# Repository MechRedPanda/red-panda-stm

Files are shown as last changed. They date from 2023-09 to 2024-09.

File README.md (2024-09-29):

# Mechanical Panda's Scanning Tunneling Microscope (STM) Design

This repository contains the design files for Mechanical Panda's Scanning Tunneling Microscope (STM), including Fusion360 CAD files, PCB engineering files, C++ firmware, and the Python software used to control the STM.

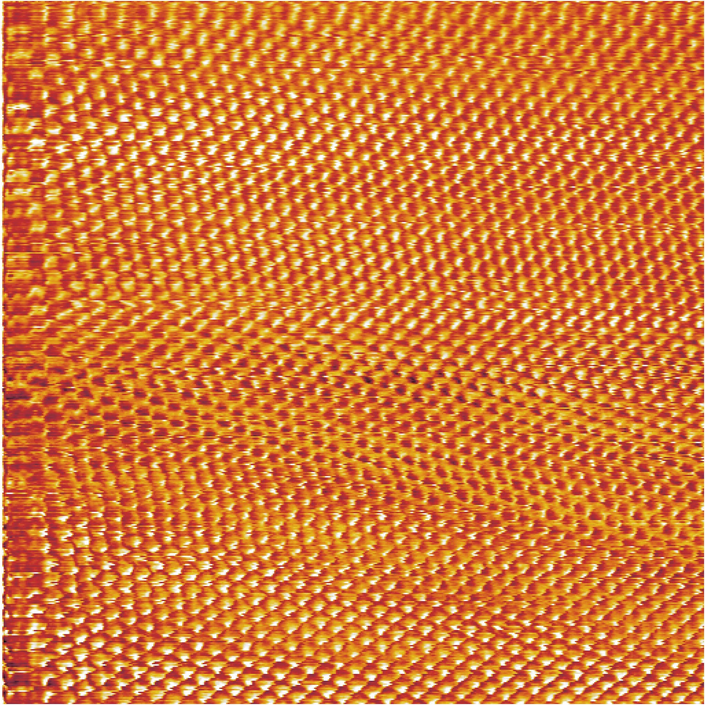
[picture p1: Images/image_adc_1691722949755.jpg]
HOPG Image of Carbon Atoms on Graphite Surface Captured by Mechanical Panda's STM

_Image of carbon atoms on the surface of graphite, showing the hexagonal structure of carbon atoms, captured by Mechanical Panda's STM._

## Project Overview

This world’s first STM design uses FDM 3D-printed parts as the main structural components. The STM can achieve atomic-level resolution, allowing it to image individual atoms.

Currently, no detailed step-by-step build tutorial is available. However, you can find a comprehensive project overview in the video on Mechanical Panda's channel:  

[**[Building a 3D Printed Atomic-Resolution Scanning Tunneling Microscope (STM) | DIY STM Explained]**]([https://www.bilibili.com/video/BV1p94y1z7jX/?share_source=copy_web&vd_source=77fd182a5182be115284bbe426944568](https://www.youtube.com/watch?v=7N3OqTEq08g))

The overall design and inspiration for this project were primarily based on Dan Berard's home-built STM project, which you can find here:  
[**[Dan Berard's Home-Built STM]**](https://dberard.com/home-built-stm/)

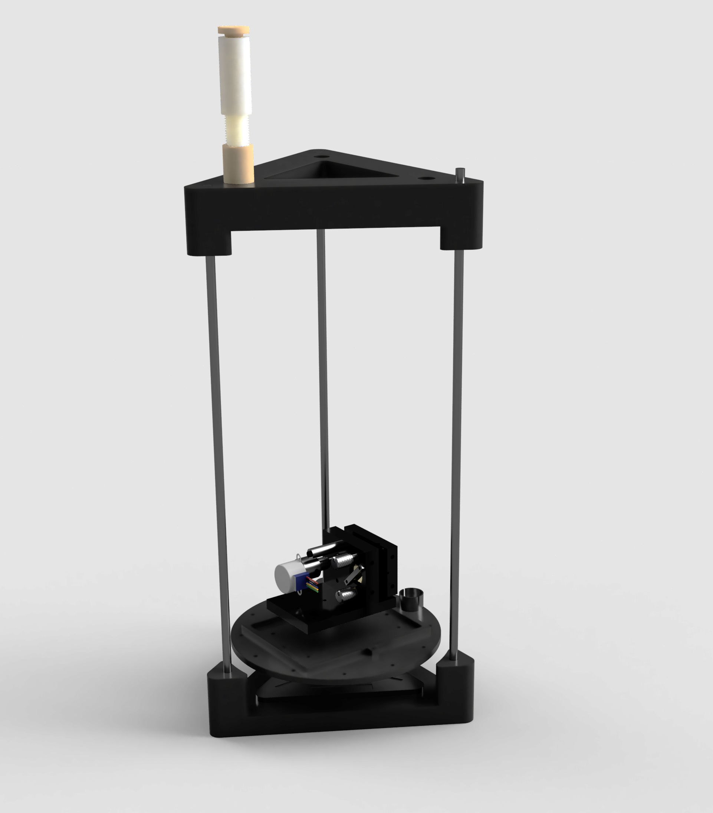
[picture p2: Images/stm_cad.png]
CAD CAD Files of the STM

_CAD files of the STM, including the STM body and vibration isolation platform._

## Repository Contents

- **Fusion360 CAD Files**: Full 3D models of the STM, including the main STM body and the vibration isolation system.
- **PCB Engineering Files**: PCB designs for the pre-amplifier and control circuit used in the STM.
- **C++ Firmware**: Microcontroller firmware for real-time control of the STM.
- **Python Control Software**: Python software for interfacing with the STM, including GUI control and data processing.

## How It Works

This STM uses a 3D-printed unimorph disk scanner, based on piezoelectric ceramics, for sub-nanometer movement. The sharp tungsten tip moves laterally across the sample's surface while measuring tunneling current to map atomic structures. A Teensy 4.1 microcontroller controls the scanner and collects scan data, while a Python program processes the data to produce high-resolution images of atomic structures.

## Acknowledgments

This project would not have been possible without the work and inspiration from Dan Berard's STM project. A huge thank you for sharing detailed reference materials that helped shape this design.

## Future Work

- **Add BOM List**: A Bill of Materials (BOM) for all the parts needed to build this STM will be added soon.

## Disclaimer

This project is experimental and requires a strong understanding of STM technology, electronics, and 3D printing. Building an STM can be challenging, but if you love pushing the boundaries of what hobbyists can achieve, this project is for you.

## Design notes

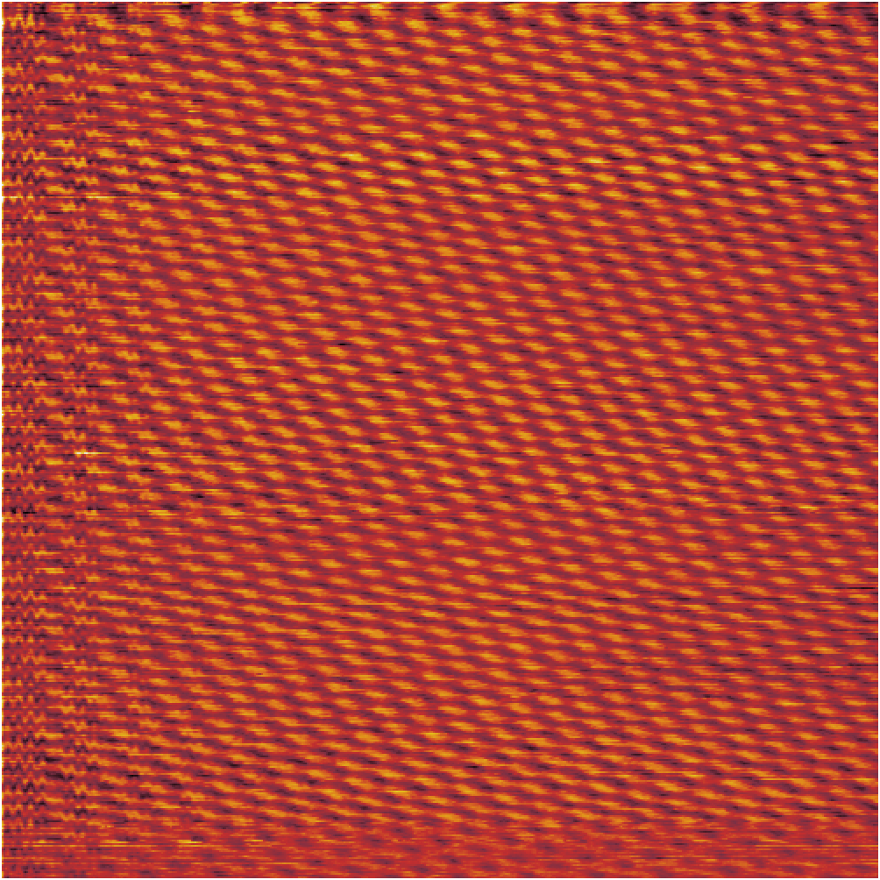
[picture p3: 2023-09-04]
Images/image_adc_1691787217383_high_res.bmp

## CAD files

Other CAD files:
CAD/STM.f3z

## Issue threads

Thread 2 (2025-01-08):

Question: Switching over to Kicad?

polymurph, 2025-01-08:
First off... I saw the [youtube](https://www.youtube.com/watch?v=7N3OqTEq08g) video. Great job. I wanted to ask if you intend to go on in the future with Kicad for the PCB designs.

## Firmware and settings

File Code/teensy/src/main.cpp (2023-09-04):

#include <Arduino.h>
#include <SPI.h> // include the SPI library
#include "stm_firmware.hpp"

#define CMD_LENGTH 4

// Serial Commnications
void serialCommand(String command, STM &stm)
{

  if (command.length() == CMD_LENGTH)
  {
    // Reset
    if (command == "RSET")
    {
      stm.reset();
    }
    // Bias control
    if (command == "BIAS")
    {
      int value = Serial.parseInt();
      stm.set_dac_bias(value);
    }
    // Stepper motor control
    if (command == "MTMV")
    {
      int value = Serial.parseInt();
      stm.move_motor(value);
    }
    // DAC control
    if (command == "DACX")
    {
      int value = Serial.parseInt();
      stm.set_dac_x(value);
    }
    if (command == "DACY")
    {
      int value = Serial.parseInt();
      stm.set_dac_y(value);
    }
    if (command == "DACZ")
    {
      int value = Serial.parseInt();
      stm.set_dac_z(value);
    }
    // ADC READ
    if (command == "ADCR")
    {
      int val = stm.read_adc();
      Serial.println(val);
    }
    // Get status
    if (command == "GSTS")
    {
      char buffer[100];
      stm.get_status().to_char(buffer);
      Serial.println(buffer);
    }

    // Approach
    if (command == "APRH")
    {
      int adc_target = Serial.parseInt();
      int steps = Serial.parseInt();
      stm.start_approach(adc_target, 10000, steps);
    }
    // MeasureIV
    if (command == "IVME")
    {
      int bias_start = Serial.parseInt();
      int bias_end = Serial.parseInt();
      int bias_step = Serial.parseInt();
      stm.generate_iv_curve(bias_start, bias_end, bias_step);
    }
    if (command == "IVGE")
    {
      stm.send_iv_curve();
    }
    // Start const current mode
    if (command == "CCON")
    {
      int adc_target = Serial.parseInt();
      stm.turn_on_const_current(adc_target);
    }
    // Turn off const current
    if (command == "CCOF")
    {
      stm.turn_off_const_current();
    }
    // Setup PID values
    if (command == "PIDS")
    {
      double Kp = Serial.parseFloat();
      double Ki = Serial.parseFloat();
      double Kd = Serial.parseFloat();
      stm.Kp = Kp;
      stm.Ki = Ki;
      stm.Kd = Kd;
    }
    if (command == "SCST")
    {
      int x_start = Serial.parseInt();
      int x_end = Serial.parseInt();
      int x_resolution = Serial.parseInt();
      int y_start = Serial.parseInt();
      int y_end = Serial.parseInt();
      int y_resolution = Serial.parseInt();
      int sample_per_pixel = Serial.parseInt();
      stm.start_scan(x_start, x_end, x_resolution, y_start, y_end, y_resolution, sample_per_pixel);
    }
    if (command == "TEST")
    {
      stm.test_piezo();
    }
    if (command == "STOP")
    {
      stm.stm_status.is_approaching = false;
      stm.stm_status.is_const_current = false;
      stm.stm_status.is_scanning = false;
    }
  }
}

void checkSerial(STM &stm)
{
  String serialString;
  if (Serial.available() > 0)
  {
    for (int i = 0; i < CMD_LENGTH; i++) // Read command with length CMD_LENGTH
    {
      // delay(1);
      char inChar = Serial.read();
      serialString += inChar;
    }
    serialCommand(serialString, stm);
  }
}

STM stm = STM();
void setup()
{
  // initialize the serial port
  Serial.begin(115200);
  // initialize SPI:
  SPI.begin();
  // Set Up SPI1 for Teensy 4.1
  SPI1.setSCK(27);
  SPI1.setCS(38);
  SPI1.setMISO(39);
  SPI1.begin();
  // Reset all;
  stm.reset();
  // Init
}

void loop()
{
  checkSerial(stm);
  stm.update();
  if (stm.stm_status.is_approaching)
  {
    stm.approach();
  }
  if (stm.stm_status.is_const_current)
  {
    stm.control_current(stm.read_adc_raw());
  }
}

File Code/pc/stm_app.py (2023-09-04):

from datetime import datetime
import tkinter as tk
from tkinter import ttk
import numpy as np
import stm_control
import time
import csv
import threading


from matplotlib.backends.backend_tkagg import (
    FigureCanvasTkAgg, NavigationToolbar2Tk)
from matplotlib.figure import Figure
from matplotlib import rcParams
rcParams.update({'figure.autolayout': True})


def save_data_to_file(filename_prefix, data_to_store: list):
    current_time_stamp = datetime.now()
    # getting the timestamp
    ts = int(datetime.timestamp(current_time_stamp)*1000)
    with open(f"{filename_prefix}_{ts}.csv", 'w', newline='') as csvfile:
        # Writing data to a file
        datawriter = csv.writer(csvfile, delimiter=',',
                                quotechar='|', quoting=csv.QUOTE_MINIMAL)
        for data in data_to_store:
            datawriter.writerow(data)


class PlotFrame(ttk.Frame):
    def __init__(self, parent, with_toobar=False,  dpi=300.0, width=400, height=400, *args, **kwargs):
        super().__init__(parent, *args, **kwargs)
        self.figure = Figure(figsize=(width / dpi*0.8,
                                      height / dpi*0.8), dpi=dpi)

        # Drawing area
        self.canvas = FigureCanvasTkAgg(
            self.figure, master=self)
        self.canvas.draw()
        self.canvas.get_tk_widget().pack(
            side='top', fill='both', expand=True)

        if with_toobar:
            self.toolbar = NavigationToolbar2Tk(
                self.canvas, self)
            self.toolbar.update()
            self.canvas.get_tk_widget().pack(side=tk.TOP, fill=tk.BOTH, expand=1)

    def add_plot(self, label=None, xlabel=None, ylabel=None,):
        self.plot = self.figure.add_subplot(
            111).plot([0, 1], [0, 0], '-', label=label)[0]
        real_time_plot_ax = self.figure.get_axes()[0]
        real_time_plot_ax.set_autoscalex_on(True)
        real_time_plot_ax.set_autoscaley_on(True)
        real_time_plot_ax.legend(loc='upper right')
        if xlabel:
            real_time_plot_ax.set(xlabel=xlabel)
        if ylabel:
            real_time_plot_ax.set(ylabel=ylabel)

    def add_image(self, image):
        self.image = self.figure.add_subplot(
            111).imshow(image, interpolation='none', norm='linear', origin="lower")

    def update_plot(self, x_data, y_data):
        self.plot.set_xdata(x_data)
        self.plot.set_ydata(y_data)
        ax = self.figure.get_axes()[0]
        ax.relim()
        ax.autoscale_view()
        # We need to draw *and* flush
        self.canvas.draw()
        self.canvas.flush_events()

    def update_image(self, image_data, extend=None):
        self.image.set_data(image_data)
        self.image.autoscale()
        if extend:
            self.image.set_extent(extend)
        # ax = self.figure.get_axes()[0]
        # ax.relim()
        # ax.autoscale_view()
        # We need to draw *and* flush
        self.canvas.draw()
        self.canvas.flush_events()

    def save_figure(self, image_path):
        self.figure.savefig(image_path)


class App(tk.Tk):
    def __init__(self):
        super().__init__()

        # Init STM
        # STM configs
        self.stm = stm_control.STM()

        self.wm_title("Panda STM")
        self.baseline_size = 700

        self.image_frame = ttk.Frame(
            self, width=self.baseline_size * 2, height=self.baseline_size * 2)
        self.image_frame.grid(row=0, column=1, padx=10, pady=5)

        # Image frame settings
        self.real_time_current_plot_frame = PlotFrame(
            self.image_frame, dpi=100.0, with_toobar=True, width=self.baseline_size, height=self.baseline_size)
        self.real_time_current_plot_frame.add_plot(
            label="current", xlabel='time(s)', ylabel='adc')
        self.real_time_current_plot_frame.grid(
            row=0, column=0, padx=10, pady=5)

        self.real_time_steps_plot_frame = PlotFrame(
            self.image_frame, dpi=100.0,  with_toobar=True, width=self.baseline_size, height=self.baseline_size)
        self.real_time_steps_plot_frame.add_plot(label="steps")
        self.real_time_steps_plot_frame.grid(
            row=0, column=1, padx=10, pady=5)

        # Image area for iv curve
        self.iv_curve_frame = PlotFrame(
            self.image_frame, dpi=100.0,  with_toobar=True, width=self.baseline_size, height=self.baseline_size)
        self.iv_curve_frame.add_plot(
            label="IVCurve", xlabel="Bias", ylabel="ADC")
        self.iv_curve_frame.grid(row=1, column=1, padx=10, pady=5)

        # Image area for scan image
        # Image frame settings
        self.scan_dacz_frame = PlotFrame(
            self.image_frame, dpi=100.0, with_toobar=True, width=self.baseline_size, height=self.baseline_size)
        init_image = np.random.rand(10, 10)
        self.scan_dacz_frame.add_image(init_image)
        self.scan_dacz_frame.grid(row=0, column=2, padx=10, pady=5)

        self.scan_adc_frame = PlotFrame(
            self.image_frame, dpi=100.0, with_toobar=True, width=self.baseline_size, height=self.baseline_size)
        init_image = np.random.rand(10, 10)
        self.scan_adc_frame.add_image(init_image)
        self.scan_adc_frame.grid(row=1, column=2, padx=10, pady=5)

        self._update_images()

        # Control pannels
        # Create left and right frames for control and display
        row_number = 0
        self.control_frames = ttk.Frame(
            self, width=self.baseline_size, height=self.baseline_size * 2)
        self.control_frames.grid(
            row=row_number, column=0, padx=10, pady=5, sticky=tk.NW)

        button_frame = ttk.Frame(self.control_frames)
        button_frame.grid(row=row_number, column=0, sticky=tk.W)

        class _DAC_Control(tk.Frame):
            def __init__(self, parent, text, default_value, cmd_func, convert_func, *args, **kwargs):
                super().__init__(parent, *args, **kwargs)
                self.cmd_func = cmd_func
                self.convert_func = convert_func
                self.input_string_var = tk.StringVar()
                self.input_string_var.initialize(default_value)
                self.input_entry = tk.Entry(
                    self, textvariable=self.input_string_var, width=15)
                self.input_entry.grid(
                    row=0, column=1, columnspan=1)

                self.display_var = tk.StringVar()
                self._update_display(default_value)

                self.display = tk.Label(self, textvariable=self.display_var)
                self.display.grid(row=0, column=2)
                self.button = ttk.Button(
                    master=self, text=text, command=self.set_value)
                self.button.grid(row=0, column=0)

            def _update_display(self, value):
                self.display_var.set(
                    str(self.convert_func(int(value))))
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

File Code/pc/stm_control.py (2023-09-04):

import serial

import numpy as np
from dataclasses import dataclass
from collections import deque
import time


@dataclass
class STM_Status:
    bias: int = 0
    dac_z: int = 0
    dac_x: int = 0
    dac_y: int = 0
    adc: int = 0
    steps: int = 0
    is_approaching: bool = False
    is_const_current: bool = False
    is_scanning: bool = False
    time_millis: int = 0

    @staticmethod
    def from_list(values):
        return STM_Status(bias=values[0],
                          dac_z=values[1],
                          dac_x=values[2],
                          dac_y=values[3],
                          adc=values[4],
                          steps=values[5],
                          is_approaching=bool(values[6]),
                          is_const_current=bool(values[7]),
                          is_scanning=bool(values[8]),
                          time_millis=values[9])

    @staticmethod
    def adc_to_amp(adc: int):
        return 1.0 * adc / 32768 * 10.24 / 100e6

    @staticmethod
    def dac_to_dacz_volts(dac: int):
        return 1.0 * (dac - 32768) / 32768 * 10.0 / 2.0

    @staticmethod
    def dac_to_dacx_volts(dac: int):
        return 1.0 * (dac - 32768) / 32768 * 10.0 / 2.0

    @staticmethod
    def dac_to_dacy_volts(dac: int):
        return 1.0 * (dac - 32768) / 32768 * 10.0 / 2.0

    @staticmethod
    def dac_to_bias_volts(dac: int):
        return 1.0 * (dac - 32768) / 32768 * 3.0

    def to_string(self):
        return """STM Status:
Bias: {} 
Z: {} 
X: {} 
Y: {} 
ADC: {} 
STEPS: {}
Appoaching: {} 
ConstCurrent: {} 
Scan: {}  
Time: {}""".format(self.bias, self.dac_z, self.dac_x, self.dac_y, self.adc, self.steps, self.is_approaching,  self.is_const_current, self.is_scanning, self.time_millis)


class STM(object):
    def __init__(self, device=None):
        self.is_opened = False
        self.busy = False
        if device:
            self.open(device)

        self.status = STM_Status()
        self.hist_length = 1000
        self.history = deque()
        self.scan_adc = None
        self.scan_dacz = None

        self.scan_config = [0, 100, 10, 0, 100, 10]
        self.scan_adc = np.ones([512, 512], dtype=np.float32)
        self.scan_dacz = np.ones([512, 512], dtype=np.float32)

    def open(self, device):
        self.stm_serial = serial.Serial(device, 115200, timeout=1)
        self.stm_serial.set_buffer_size(rx_size=128000, tx_size=128000)
        self.is_opened = True

    def get_status(self):
        if self.busy:
            return
        if self.is_opened:
            if self.busy:
                print('busy')
                return self.history[-1]
            try:
                self.send_cmd('GSTS')
                status_str = self.stm_serial.readline().decode()
                status_value = status_str.split(',')
                status_value = [int(x) for x in status_value]
                self.status = STM_Status.from_list(status_value)
            except:
                print('no response')
                return self.history[-1]
        else:
            self.status = STM_Status()
        self.history.append(self.status)
        if len(self.history) > self.hist_length:
            self.history.popleft()

        return self.status

    def reset(self):
        self.send_cmd('RSET')
        self.clear()

    def clear(self):
        self.history = deque()

    def send_cmd(self, cmd):
        if self.is_opened:
            self.stm_serial.write(cmd.encode())

    def move_motor(self, steps):
        self.send_cmd('MTMV {steps}')

    def approach(self, target_dac, steps):
        self.send_cmd(f'APRH {target_dac} {steps}')

    def stop(self):
        self.send_cmd('STOP')

    def measure_iv_curve(self, dac_start, dac_end, dac_step):
        self.send_cmd(f'IVME {dac_start} {dac_end} {dac_step}')
        # Wait for 0.1s for the STM to response
        time.sleep(2)
        return self.get_iv_curve()

    def get_iv_curve(self):
        iv_curve_values = [0, 0]
        if self.is_opened:
            self.busy = True
            time.sleep(1)
            self.send_cmd('IVGE')
            data_str = self.stm_serial.readline().decode()
            data = data_str.split(',')
            if data[0] == "IV":
                iv_curve_values = [int(x) for x in data[1:]]
        self.busy = False
        print(iv_curve_values)
        return iv_curve_values

    def set_bias(self, value):
        self.send_cmd(f"BIAS {value}")

    def set_dacz(self, value):
        self.send_cmd(f"DACZ {value}")

    def set_dacx(self, value):
        self.send_cmd(f"DACX {value}")

    def set_dacy(self, value):
        self.send_cmd(f"DACY {value}")

    def turn_on_const_current(self, target_adc):
        self.send_cmd(f"CCON {target_adc}")

    def turn_off_const_current(self):
        self.send_cmd(f"CCOF")

    def set_pid(self, Kp, Ki, Kd):
        self.send_cmd(f"PIDS {Kp} {Ki} {Kd}")

    def start_scan(self, x_start, x_end, x_resolution, y_start, y_end, y_resolution, sample_number):
        self.busy = True
        self.scan_config = [x_start, x_end,
                            x_resolution, y_start, y_end, y_resolution]
        self.send_cmd(
            f"SCST {x_start} {x_end} {x_resolution} {y_start} {y_end} {y_resolution} {sample_number}")

        self.scan_adc = np.ones([x_resolution, y_resolution], dtype=np.float32)
        self.scan_dacz = np.ones(
            [x_resolution, y_resolution], dtype=np.float32)

        current_line = ''

        def _process_full_line(full_line):
            # print(full_line)
            data = full_line.split(',')
            data_type = data[0]
            if data_type == "A":
                x_i = int(data[1])
                data_content = data[2:]
                data_content = [int(x) for x in data_content]
                self.scan_adc[x_i, :] = data_content
            if data_type == "Z":
                x_i = int(data[1])
                data_content = data[2:]
                data_content = [int(x) for x in data_content]
                self.scan_dacz[x_i, :] = data_content
            if data_type == "D":
                return True
            return False
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

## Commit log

2023-09-04 Delete teensy directory
    cleanup
2023-09-04 Add files via upload
    add code
    [STM.f3z]
2023-09-04 Add files via upload
    add pcb
2023-11-04 Add files via upload
    add a pdf of schematic files
2023-11-04 Add files via upload
    add a different version of the pcb file. I did not test this file.
